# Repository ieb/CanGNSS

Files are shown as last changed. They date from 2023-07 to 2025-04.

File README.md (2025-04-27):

# NMEA2000 GNSS Receiver

A NMEA2000 device to provide rapid position and COG SOG update as well as other GNSS information including satelite data.

# PGN messages and rates.

* 129025L Position Rapid update 5Hz
* 129026L COG/SOG Rapid Update 2.5Hz
* 129029L Position data 1Hz
* 126992L System Time, 1Hz
* 129539L GNSS DOPs 1Hz
* 129540L GNSS Satellites in View 0.5Hz
* 127258L Magnetic Variation 1Hz

Magnetic variation is calculated every 60s from WMN2020 World model coefficients.

# Hardware

* Attiny3224 MCU
* UBlox M8N module pre configured at 19200 Baud with UBX messages.
* MCP 2515 CAN driver with TJ1050 Transceiver

# Code

Starts up, establishes CAN connectivity then reads UBX messages as they are produced and transfers them directly onto the NMEA200 bus.  There is a monitoring UART that runs at 115200 which can be used to see log messages and reboot. Press h to get a menu. The WNM2020 model takes 63ms to calculate which is long enough for a standard 64 byte UART buffer to overflow. This code requires a patched megaTinyCode code base with a 256 byte UART buffer.

# Pins

                                ANT
      --------------------------------
      |          A B C D E           |
      | F                            |
      | G                            |
      | H                            |
      | I                            |
      |                     j k l m  |
      --------------------------------

* A +5v   
* B 0v
* C UDPI
* D RX Console
* E TX Console

* F 12V - CAN
* G 0V
* H CAN-L
* I CAN-H

* j 0v
* k TX Ublox
* l RX Ublox
* m 5v Ublox

# Settings.

The MCU can program the device to its standard settings. press h to get the menu on the console. For more advanced settings u-center or pyGPSClient can be used, but first the MCU Uart connected to the Ublox module must be disabled.

Press u to disable the Uart, then without turning the device off, connect to the Ubloc TX and RX pins. The Uart will be re-enabled on reboot or power cycle.

I have found pyGPSClient to be much easier than u-center as Windows tends to grab the comp ports and GPS stream making it
almost impossible to connect u-center. (tips welcome).  So I use pyGPSClient on a Ubuntu VM running in OSX. First connect with screen to get the console

    screen /dev/ttyUSB0 115200

pres h to get the menu and u to disconnect the UART. The Ctrl-a + k  to exit screen.

Then connect pyGPSClient to the ublox via a serial and reconfigure as required.

## Expected setup.

* Baud 19200
* UBX Messages only, no NMEA

The satelite setup blow gives about 1m 3D accuracy without SBAS corrections, and slightly less once the SBAS
corrections are received. Should probably write this into code.
* CFG-GNSS  also set in code
* msgVer 0, mumTrkChHw 32 (read only), mumTrkChUse 32, numConfigBlocks 7
* gnssId 0 (GPS), res 4, max 16, enable 1, mask 1 eg L1C/A 1,575.42MHz
* gnssId 1 (SBAS), res 2, max 4, enable 1, mask 1 eg L1C/A 1,575.42MHz
* gnssId 2 (Galileo), res 4, max 8, enable 1, mask 1 eg E1 1,575.42MHz
* gnssId 3 (BelDou) disabled 0,0,0,0
* gnssId 4 (IMESS) diabled 0,0,0,0
* gnssId 5 (QZSS) res 1, max 1, enable 1 mask 1, L1C/A  1,575.42MHz
* gnssId 6 (GLonas) res 2, max 5 enable 1, mask 1 L1
*
* CFG-ITMF,ection Jamming det enabled on active antena, all else defaults.
* CFG_NAV5 set modes to sea
* CFG-SBAS as default enable  1 (ignored), test 0, range 1, diffCorr 1, integrety 0, maxSBAS 3
* PRN 120, 123, 127-129, 133, 135-138

* Also set in code
* CFG_RATE Solution interval 200ms, measurement ratio 5, UTC. 
* NAV setup all off except
* NAV-DOP 6
* NAV-POSLLH 1
* NAV-PVT 5
* NAV-SAT 9
* NAV-VELNED 2

# PCB

The PCM is designed in KiCad (ancient version), and milled on a CNC miller. The attiny3224 is underneath the ublox module, which has a ground plane on the bottom layer.

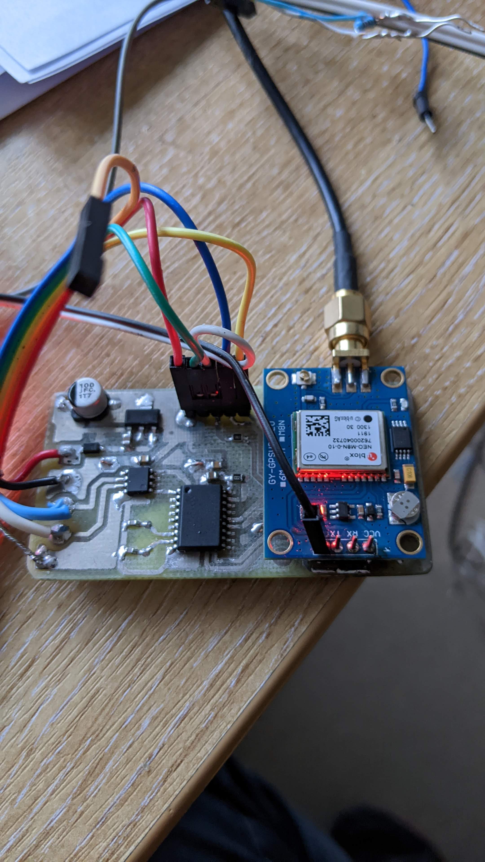
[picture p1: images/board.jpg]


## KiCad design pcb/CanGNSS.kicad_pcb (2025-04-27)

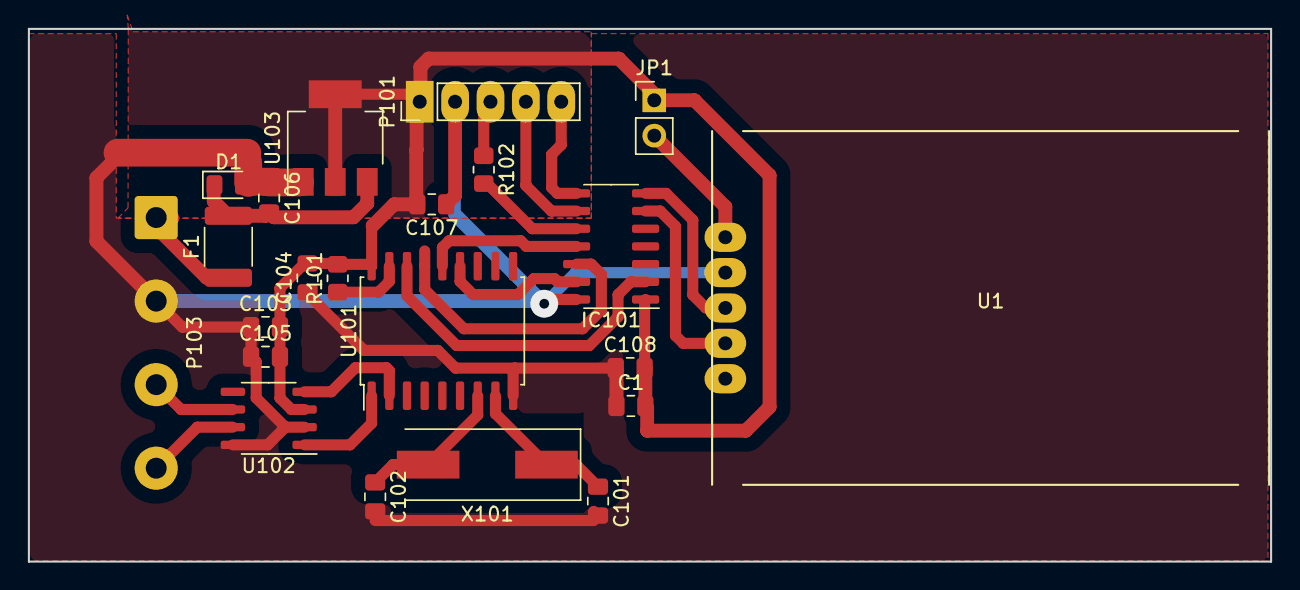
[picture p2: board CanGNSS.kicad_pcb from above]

Board: 2 copper layers, 89.2 x 38.3 mm, 22 parts (0 on the bottom side), 22 nets.

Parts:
C1, C103, C106, C107: 10uF; C_0805_2012Metric_Pad1.18x1.45mm_HandSolder
C101, C102: 22pF; C_0805_2012Metric_Pad1.18x1.45mm_HandSolder
C104, C105, C108: 100nF; C_0805_2012Metric_Pad1.18x1.45mm_HandSolder
D1: D; D_0805_2012Metric_Pad1.15x1.40mm_HandSolder
F1: Polyfuse_Small; Fuse_1812_4532Metric_Pad1.30x3.40mm_HandSolder
IC101: ATTINY3224-SS; SO-14_3.9x8.65mm_P1.27mm
JP1: Jumper_2_Bridged; PinHeader_1x02_P2.54mm_Vertical
P101: Debug; PinHeader_1x05_P2.54mm_Vertical
P103: CAN; SolderWire-1.5sqmm_1x04_P6mm_D1.7mm_OD3mm
R101: 10K; R_0805_2012Metric_Pad1.20x1.40mm_HandSolder
R102: 470R; R_0805_2012Metric_Pad1.20x1.40mm_HandSolder
U1: neo-m8n-module-mini
U101: MCP2515; SOIC-18W_7.5x11.6mm_P1.27mm
U102: TJA1050; SO-8_3.9x4.9mm_P1.27mm
U103: NCP1117ST50T3G; SOT-223-3_TabPin2
X101: 16MHz; Crystal_SMD_HC49-SD

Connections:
5V: C1.2, C103.2, C104.2, C105.2, C107.2, C108.2, IC101.1 (VCC), JP1.1 (A), P101.1, R101.2, U101.18 (Vdd), U102.3 (Vcc), U103.2 (VO)
5Vswitched: JP1.2 (B), U1.5 (Vcc)
12v: F1.1, P103.1
CANCS: IC101.2 (PA4(AIN4/XDIR/SS)), U101.16 (CS)
CANH: P103.4, U102.7 (CanH)
CANL: P103.3, U102.6 (CanL)
DEBUG_RX: IC101.9 ((AIN11/SCL)PB0), P101.4
DEBUG_TX: IC101.8 ((AIN10/SDA)PB1), P101.5
GND: C1.1, C101.2, C102.2, C103.1, C104.1, C105.1, C106.1, C107.1, C108.1, D1.2 (A), IC101.14 (GND), P101.2, P103.2, U1.4 (Gnd), U101.9 (GND), U102.2 (GND), U102.8 (S), U103.1 (GND)
GPSRX: IC101.6 (PB3(RX0/TOSC1)), U1.2 (Rx)
GPSTX: IC101.7 (PB2(Tx0/TOSC2/EVOUTB)), U1.3 (Tx)
MISO: IC101.12 ((RX1/MISO/AIN2)PA2), U101.15 (SO)
MOSI: IC101.11 ((TX1/MOSI/AIN1)PA1), U101.14 (SI)
unnamed: C106.2, D1.1 (K), F1.2, U103.3 (VI)
unnamed: IC101.10 ((UDPI/RESET)_PA0), R102.2
unnamed: U101.2 (CANRX), U102.4 (RXD)
unnamed: U101.1 (CANTX), U102.1 (TXD)
unnamed: C101.1, U101.8 (OSC1), X101.1
unnamed: C102.1, U101.7 (OSC2), X101.2
unnamed: R101.1, U101.17 (RESET)
SCK: IC101.13 ((XCK/SCK/AIN3)PA3), U101.13 (SCK)
UDPI: P101.3, R102.1

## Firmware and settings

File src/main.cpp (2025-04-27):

#include <Arduino.h>
#include <Wire.h>
#include <SPI.h>
#include "SmallNMEA2000.h"
#include "commandline.h"
#include "GNSSReciever.h"
#include "UBXReader.h"
#include "SoftwareSerial.h"

/*
Reads messages from a UBLOX receiver and on receipt translates into a 
NMEA2000 Message. Does not store any messages and requires the UBLOX
receiver to have been pre-configured with the required messages.
Additional messages read will be dropped. Messages that are too long
will be skipped.
*/


#ifdef MEGATINYCORE_MCU            
#define SNMEA_SPI_CS_PIN PIN_PA4
#define SOFT_RX_PIN PIN_PB0
#define SOFT_TX_PIN PIN_PB1
#else
#define SNMEA_SPI_CS_PIN 4
#define SOFT_RX_PIN 2
#define SOFT_TX_PIN 3
#endif

SoftwareSerial console(SOFT_RX_PIN, SOFT_TX_PIN);
Print *consolePtr = &console;

#define CODE_VERSION "0817f57"


const SNMEA2000ProductInfo productInfomation PROGMEM={
                                       1300,                        // N2kVersion
                                       46,                         // Manufacturer's product code
                                       "5Hz GNSS",    // Manufacturer's Model ID
                                       CODE_VERSION,     // Manufacturer's Software version code
                                       "5Hz GNSS",      // Manufacturer's Model version
                                       "0000002",                  // Manufacturer's Model serial code
                                       0,                           // SertificationLevel
                                       1                            // LoadEquivalency
};
const SNMEA2000ConfigInfo configInfo PROGMEM={
      "5Hz GNSS Receiver",
      "Luna Technical Area",
      "https://github.com/ieb/CanGNSS"
};

uint8_t pgnEnableRegister = 0xff;


const unsigned long txPGN[] PROGMEM = { 
    126992L, // System Time, 1Hz
    129025L, // Position Rapid update 5Hz
    129026L, // COG/SOG Rapid Update 4Hz
    129029L, // Position data 1Hz
    129539L, // GNSS DOPs 1Hz
    129540L, // GNSS Satellites in View
    127258L, // Magnetic Variation
    SNMEA200_DEFAULT_TX_PGN
};





const unsigned long rxPGN[] PROGMEM = { 
  SNMEA200_DEFAULT_RX_PGN
};

const SNMEA2000DeviceInfo devInfo = SNMEA2000DeviceInfo(
  02,   // device serial number
  145,  // GNSS
  60 // Navigation
);

#define DEVICE_ADDRESS 30
#define DEVICE_SERIAL_NUMBER 45

GNSSReciever gnssReciever = GNSSReciever(DEVICE_ADDRESS, 
          &devInfo, 
          &productInfomation, 
          &configInfo, 
          &txPGN[0], 
          &rxPGN[0],
          SNMEA_SPI_CS_PIN,
          &console
);


CommandLine commandLine = CommandLine(&console);

#define MESSAGE_BUFFER_SIZE 512
uint8_t messageBuffer[MESSAGE_BUFFER_SIZE];
UBXReader ubxReader(&console, &messageBuffer[0], MESSAGE_BUFFER_SIZE);


void factoryReset() {
  ubxReader.factoryReset();
}

void saveConfig() {
  ubxReader.saveConfig();
}

void disconnectUBX() {
  ubxReader.end();
  console.println(F("UBX disconnected, reboot to reconnect"));
}

uint8_t diagnostics = 0;
#define INFO_ENABLED  (diagnostics > 0)
#define DEBUG_ENABLED  (diagnostics > 1)

void changeDiagnostics() {
  diagnostics = (diagnostics+1)%3;
  if ( DEBUG_ENABLED ) {
    console.println(F("DEBUG ON"));
    gnssReciever.setDiagnostics(true);
  } else if (INFO_ENABLED) {
    console.println(F("INFO ON"));
    gnssReciever.setDiagnostics(false);
  } else {
    console.println(F("INFO OFF"));
    gnssReciever.setDiagnostics(false);
  }
}




void setup() {
  console.begin(115200);
  console.print(F("GNSS Receiver start version:"));
  console.println(F(CODE_VERSION));
  commandLine.begin();

  // required to avoid an error initialising the can bus.
  pinMode(SNMEA_SPI_CS_PIN, OUTPUT);

  // If PA7 is pulled high, then the 
  // device starts up emitting serial messages on RX1/TX1
  // pin X low then the device starts with the Can device using SPI.
  gnssReciever.setSerialNumber(DEVICE_SERIAL_NUMBER);
  gnssReciever.setDeviceAddress(DEVICE_ADDRESS);
  gnssReciever.open(MCP_16MHz);
  int retries = 0;
  while ( retries < 5 && !gnssReciever.open(MCP_16MHz) ) {
    console.println(F("Failed to start CAN, retrying in 5s"));
    delay(5000);
    retries++;
  }
  if ( retries == 5 ) {
    console.println(F("Failed to start CAN, no CAN"));
  }
  ubxReader.begin(57600);
  console.println(F("Running..."));
}

void dumpMessage(UbloxHeader *message) {
  static uint16_t lastReadCalls = 0;
  static uint16_t lastBytesRead = 0;
  console.print(F("cls: 0x"));
  console.print(message->messageClass, HEX);
  console.print(F(" id: 0x"));
  console.print(message->messageId, HEX);
  console.print(F(" len: "));
  console.print(message->payloadLength);  
  console.print(F(" state:"));
  console.print(Serial.getStatus(),HEX);
  console.print(F(" reads:"));
  UBXReaderMetrics * metrics = ubxReader.getMetrics();
  uint16_t reads = metrics->readCalls-lastReadCalls;
  lastReadCalls = metrics->readCalls;
  console.print(reads);
  console.print(F(" readsize:"));
  if ( reads > 0) {
    uint16_t readSize = (metrics->bytesRead-lastBytesRead)/reads;
    console.println(readSize);
  } else {
    console.println(F("n/a"));
  }
  lastBytesRead = metrics->bytesRead;
}

void dumpMetrics(bool force) {
  static unsigned long tlast = 0;
  unsigned long now = millis();
  if ( force || (now-tlast) > 5000 ) {
    UBXReaderMetrics * metrics = ubxReader.getMetrics();
    GNSSMetrics * gnssMetrics = gnssReciever.getMetrics();
    tlast = now;
    console.print(F("metrics bread:"));
    console.print(metrics->bytesRead);
    console.print(F(" restarts: "));
    console.print(metrics->bufferRestarts);
    console.print(F(" received: "));
    console.print(metrics->messageRecieved);
    console.print(F(" errors: "));
    console.print(metrics->messageError);
    console.print(F(" overflow: "));
    console.print(metrics->messageOverflow);
    console.print(F(" posllh: "));
    console.print(gnssMetrics->posllh);
    console.print(F(" velned: "));
    console.print(gnssMetrics->velned);
    console.print(F(" pvt: "));
    console.print(gnssMetrics->pvt);
    console.print(F(" dop: "));
    console.print(gnssMetrics->dop);
    console.print(F(" sat: "));
    console.print(gnssMetrics->sat);
    console.print(F(" unknown: "));
    console.println(gnssMetrics->unknown);
  }

}

/*
typedef struct _GNSSFix {
    uint8_t sid;
    uint8_t fixType;
    uint8_t methodType;
    uint8_t actualMode;
    uint8_t valid;
    uint8_t numSV;
    uint8_t numSvu;
    int16_t pdop;
    int16_t hdop;
    int16_t vdop;
    int16_t tdop;
    uint16_t daysSince1970;
    uint32_t secondsSinceMidnight;
    int32_t lat;
    int32_t lon;
    int32_t height;
    int32_t latitude_scaled;
    int32_t longitude_scaled;
    int32_t heading_scaled;
    uint32_t ground_speed;
    float variation;
} GNSSFix;
*/
void dumpFix(bool force) {
  static unsigned long tlast = 0;
  unsigned long now = millis();
  if ( force || (now-tlast) > 2000 ) {
    GNSSFix  * fix = gnssReciever.getFix();

    tlast = now;
    console.print(F("fix lat:"));
    console.print((double)(fix->lat)*(1.0E-7),7);
    console.print(F(" lon:"));
    console.print((double)(fix->lon)*(1.0E-7),7);
    console.print(F(" cog:"));
    console.print((double)(fix->heading_scaled)*(1.0E-5),1);
    console.print(F(" sog:"));
    console.print((double)fix->ground_speed*0.0194384,3);
    console.print(F(" flags:"));
    console.print(fix->flags);
    console.print(F(" sats:"));
    console.print(fix->numSvu);
    console.print(F(" pdop:"));
    console.print(fix->pdop);
    console.print(F(" daysSince1970:"));
    console.print(fix->daysSince1970);
    console.print(F(" height:"));
    console.println(fix->height);
  }
}



void dumpStatus() {
  gnssReciever.dumpStatus();
  dumpMetrics(true);
  dumpFix(true);
}


void loop() {
  static uint16_t calls = 0;
  calls++;
  eUbloxMessageStatus status = ubxReader.read();
  UbloxHeader * message = ubxReader.getMessage();
  switch(status) {
    case msgStatusOk:
      if ( DEBUG_ENABLED ) {
        console.print(calls);
        console.print(F(" Ok"));
        dumpMessage(message);      
      }
      gnssReciever.update(message);
      calls = 0;
      break;
    case msgStatusBadCheckSum:
      console.print(calls);
      console.println(F(" Bad checksum "));
      dumpMessage(message);
      calls = 0;
      break;
    case msgStatusOverflow:
      console.print(calls);
      console.println(F(" Overflow "));
      //dumpMessage(message);
      calls = 0;
      break;
    case msgAck:
      console.print(calls);
      console.println(F(" ACK"));
      calls = 0;
      break;
    case msgNak:
      console.print(calls);
      console.println(F(" NAK"));
      calls = 0;
      break;
    case msgIncomplete:
//      console.print(".");
      break;
  }
  gnssReciever.processMessages();
  commandLine.checkCommand();
  if ( INFO_ENABLED ) {
    dumpMetrics(false);    
    dumpFix(false);
  }
}

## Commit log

2023-06-17 Added VELNED and started NMEA2000 messages
    [CanGNSS.sch]
2023-06-25 Added ability to configure at startup
    [CanGNSS.kicad_pcb, CanGNSS.sch]
2023-07-05 Enabled reconfig in case the BBR fails
    [main.cpp]
2023-07-06 And print it out
2023-07-16 Fixes to COG and SOG
    [main.cpp]
2025-04-27 Updated board and config
    [CanGNSS.kicad_pcb]
